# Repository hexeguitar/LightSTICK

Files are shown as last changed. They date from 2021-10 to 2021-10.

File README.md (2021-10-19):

# LightStick

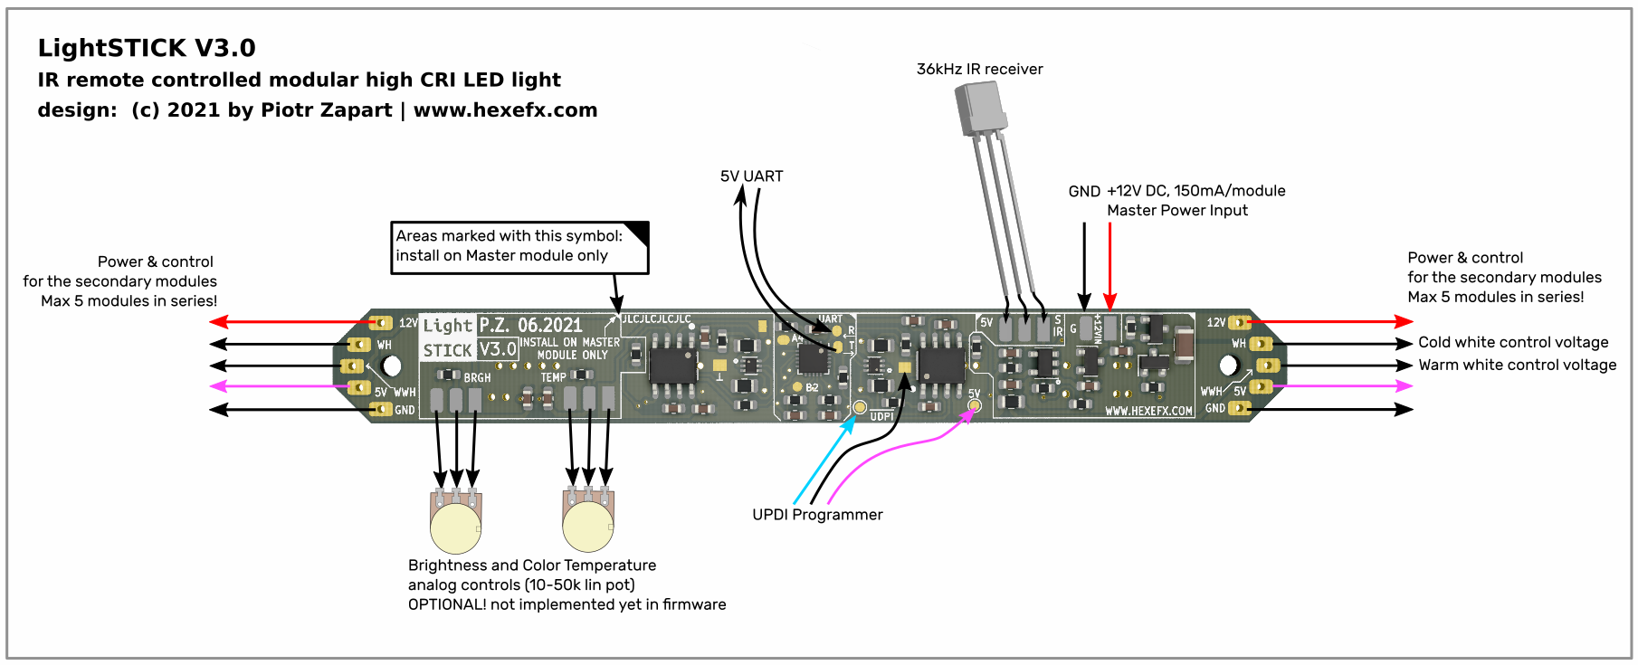
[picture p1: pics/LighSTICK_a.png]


## Features:  
- High CRI >95 dual color white leds (cold/warm).
- Modular system with one Master module and up to 4 secondary modules.
- Linear constant current LED drivers.
- IR remote control (brightness, color, presets).
- Optional analog control using potentiometers (not implemented yet).
- Power saving OFF mode.
- Current consumption: about 300mA per module in full brightness.
  
## Background/design:
Traditional and common studio lights used in photography and filming usually use a high current PWM to control the brightness. For my use in filming analog instruments and effects (often high gain ones) i really needed something quiet and as noise/EMI free as possible.  
That's how the **LightSTICK** modular light was born - it uses linear constant current drivers for the LEDs and a DC control voltage to set the brightness and the color temperature.  
## Modularity
The design is modular, one "Master" module, consisting the MCU and IR receiver can control up to 4 additional secondary modules connected via a 5 wire bus:  
* 12V supply for the LEDs
* 5V supply for the constant current drivers / control voltage reference
* **WH** - cold white control voltage
* **WWH** - warm white control voltage
* GND  
## LED type  
LEDs used in the LightSTICK are manufactured by the LEDGUON company, obtainable through their direct store at Aliexpress.  
The part number is: **JH-5054WWW12S35-T8A-97**
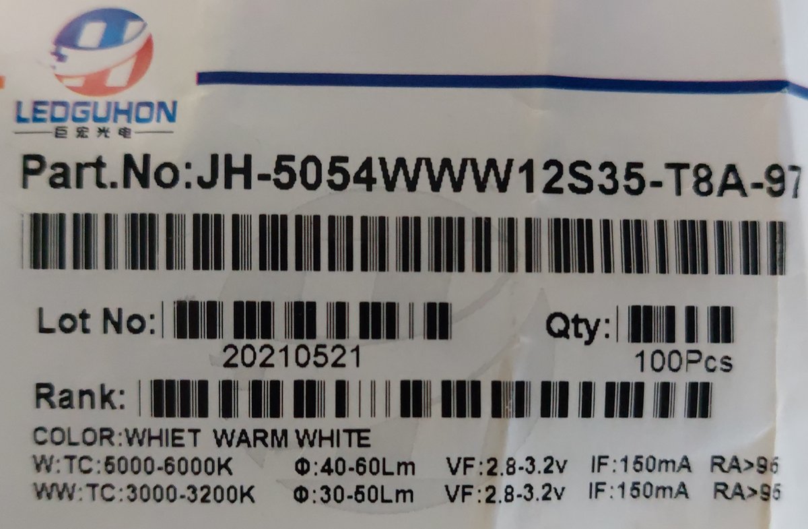
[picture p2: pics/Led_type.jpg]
  

## PCB design
PCB is designed as 4 layer one, using the most of the top layer for heat dissipation.  
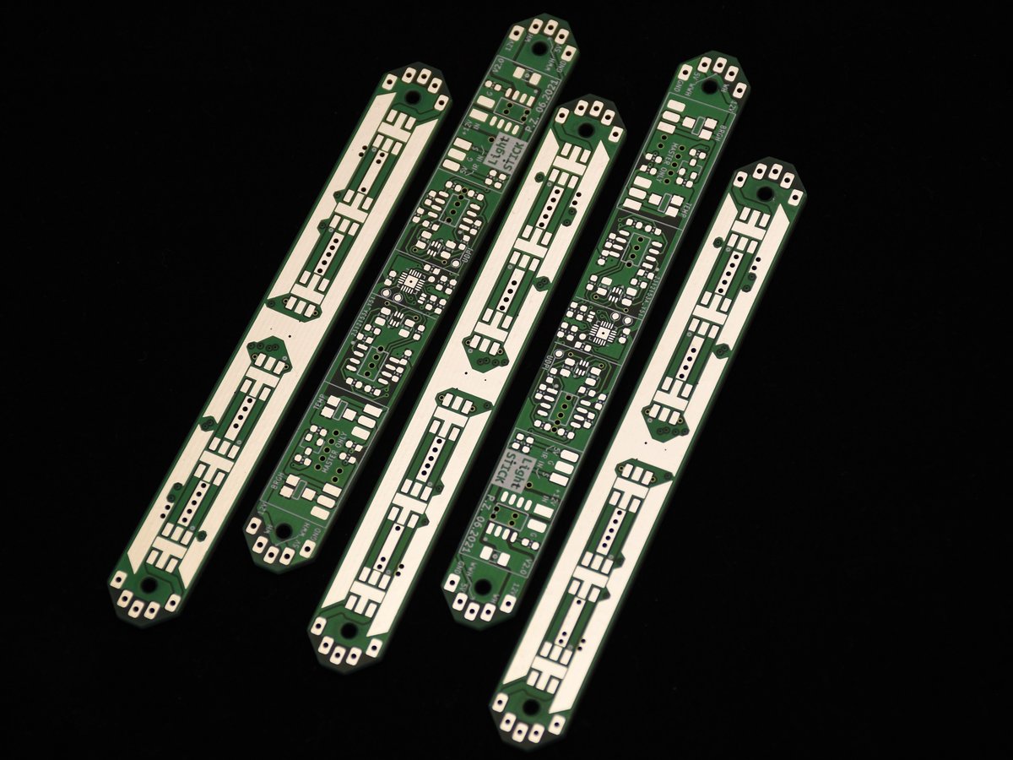
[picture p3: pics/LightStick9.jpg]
  
## Firmware
LightSTICK uses ATtiny806 as it's MCU. The firmware is available as Platformio project and compiled with Arduino framework. Only one library is required and included in the /lib folder: **Arduino-IRremote**, which has been modified to support the ATtiny806 chip.  

### Pot support
Initially i planned to use two potentiometers as control input for the brightness and color temp. However, during the firmware development the IR remote control turned out to be much more useful, hence i went that route. Nevertheless, the footprint for pots are provided and a basic interrupt driven ADC read functionality is implemented in case some would need it. Expanding the firmware should not be a hard task.  

### IR remote control
The easiest way to adapt an existing tv/camera remote as LightSTICK controller is to analyze it using a generic arduino board and one of the examples from the **Arduino-IRremote** library (ie. "Receive Demo). Simply write down the protocol of the remote and all the command codes for each button. In my case of a small remote from an old TC card the results were as follows:  
```
Protocol:           RC5

...
+:                  Command=0x3 Toggle=1 Raw-Data=0x19C3
                    Command=0x3 Raw-Data=0x11C3

-:                  Command=0x9 Toggle=1 Raw-Data=0x19C9
                    Command=0x9 Raw-Data=0x11C9

Up:                 Command=0x6 Toggle=1 Raw-Data=0x19C6
                    Command=0x6 Raw-Data=0x11C6
                    
Down:               Command=0xC Toggle=1 Raw-Data=0x19CC
                    Command=0xC Raw-Data=0x11CC

1:                  Command=0xF Toggle=1 Raw-Data=0x19CF
                    Command=0xF Raw-Data=0x11CF

2:                  Command=0x15 Raw-Data=0x11D5
                    Command=0x15 Toggle=1 Raw-Data=0x19D5

3:                  Command=0x10 Toggle=1 Raw-Data=0x19D0
                    Command=0x10 Raw-Data=0x11D0

4:                  Command=0x18 Raw-Data=0x11D8
                    Command=0x18 Toggle=1 Raw-Data=0x19D8

5:                  Command=0x1B Toggle=1 Raw-Data=0x19DB
                    Command=0x1B Raw-Data=0x11DB
...
```
The command codes are then used in the IR command table (*`remote.h`* file)
```c++
/**
 * @brief IR remote command table. 
 * 
 */
typedef enum
{
    CMD_IDLE            = 0x00,
    CMD_PWR_TGL         = 0x39,     // key POWER
    CMD_BRIGHT_INC      = 0x03,     // key +
    CMD_BRIGHT_DEC      = 0x09,     // key -
    CMD_BRIGHT_MAX      = 0x30,     // key PLAY
    CMD_COLOR_WARMER    = 0x06,     // key UP
    CMD_COLOR_COLDER    = 0x0C,     // key DOWN
    CMD_COLOR_WARM      = 0x33,     // key FWD
    CMD_COLOR_COLD      = 0x2D,     // key REW
    CMD_PRESET_0        = 0x27,     // key 0
    CMD_PRESET_1        = 0x0F,     // key 1
    CMD_PRESET_2        = 0x15,     // key 2
    CMD_PRESET_3        = 0x10,     // key 3
    CMD_PRESET_4        = 0x18,     // key 4
    CMD_PRESET_5        = 0x1B,     // key 5
    CMD_PRESET_6        = 0x1E,     // key 6
    CMD_PRESET_7        = 0x11,     // key 7
    CMD_PRESET_8        = 0x21,     // key 8
    CMD_PRESET_9        = 0x12,     // key 9
    CMD_RESET_MCU       = 0x3C,     // key STOP
    CMD_STORE_PRESET    = 0x36      // key REC
}ir_cmd_t;
```  
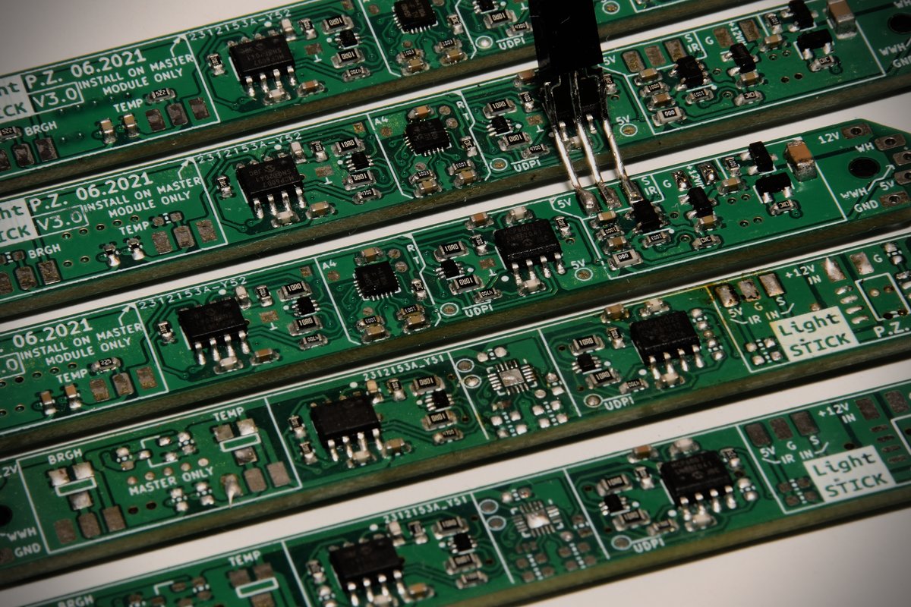
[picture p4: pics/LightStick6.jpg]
  
### Low power design  
Both, the electronics and the firmware implements low power design techniques making the LightSTICK useful as battery operated device, too.  
In **OFF** state the global 12V and 5V power busses are disabled, the MCU is in power off state, practically leaving the IR receiver as a single powered on device.

### Programming
ATtiny806 uses UPDI protocol for programming the flash. The programmer should be connected to the pads marked !UPDI, 5V and GND, depending on the used device. Programmers like the Atmel-ICE require the 5V VDD to set the proper logic level.  
An UPDI programmer can be also made of a generic Arduino board. In that case make sure the board runs on 5V, only the UPDI and GND connections will be required.  
The `platformio.ini` file assumes the Atmel-ICE programmer. This file has to be modified if another type of programmer is used.      
First use the following command in Platformio to set the correct fuse values:  
```
pio run -t fuses -e set_fuses
```
and then normally upload the firmware.  

## Applications  
Cheap "book lamp" rebuilt into remote controlled high CRI light for macro photography. Improved thermals by mounting the pcbs on two pieces of 15mm wide alu flat profile with 3mm thick silicon pad isolation.
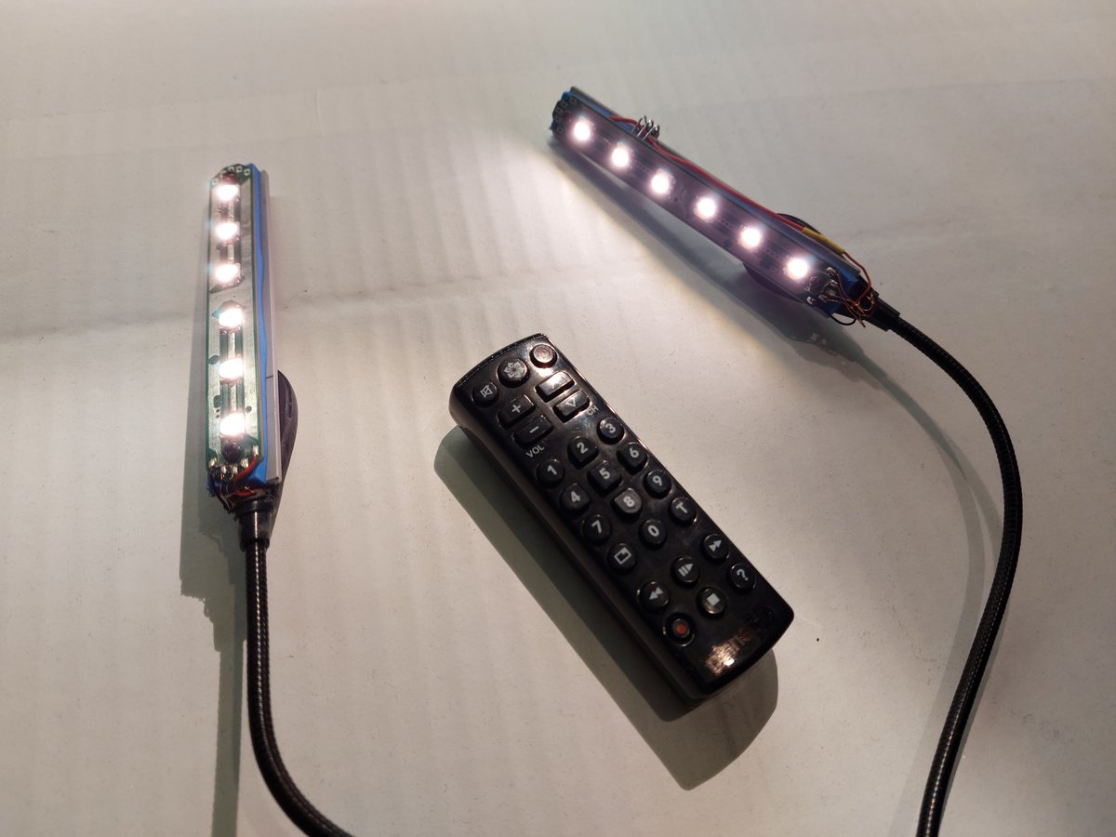
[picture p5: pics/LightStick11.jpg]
  
A ring of 5 LightSTICKs used as source of indirect light in macro photography.
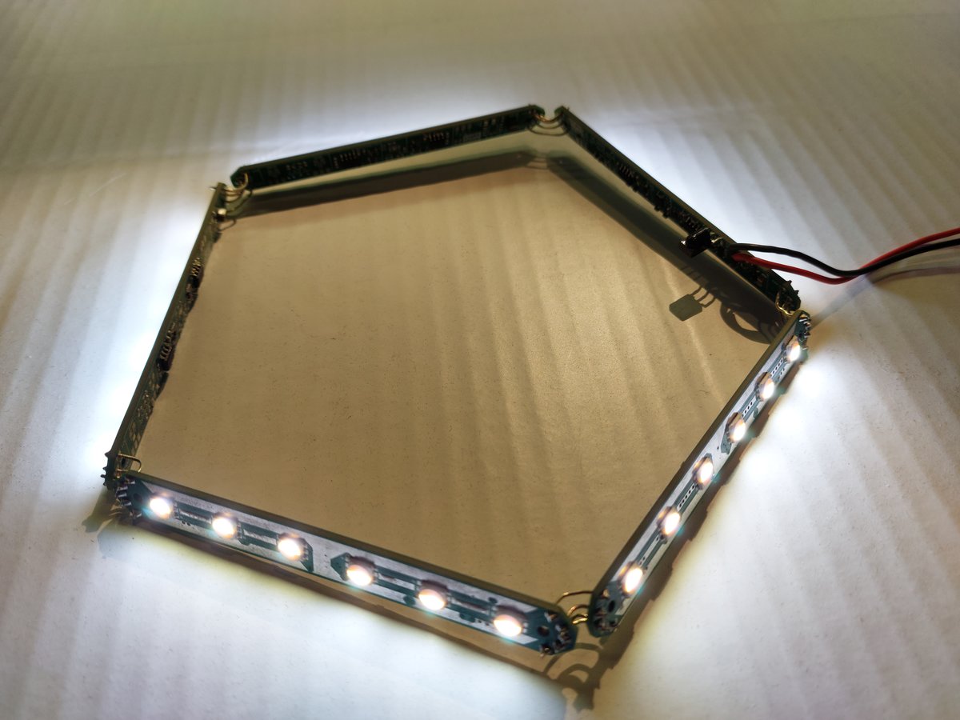
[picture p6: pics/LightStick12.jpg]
  
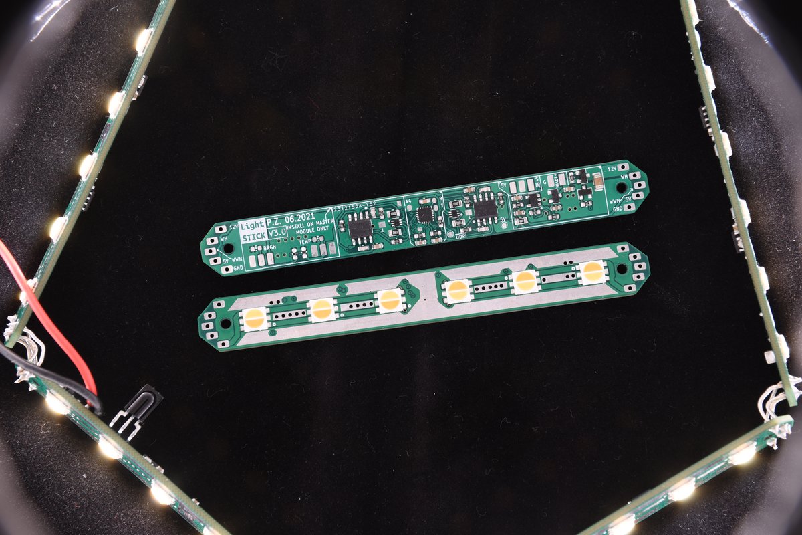
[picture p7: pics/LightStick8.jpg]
  

----  
Copyright 2021 by Piotr Zapart  
www.hexefx.com

[pic1]: pics/LighSTICK_a.png "LightSTICK main"
[pic2]: pics/Led_type.jpg "LEDs used in the project"
[pic3]: pics/LightStick9.jpg "LightSTICK"
[pic4]: pics/LightStick8.jpg "LightSTICK"
[pic5]: pics/LightStick6.jpg "LightSTICK"
[pic6]: pics/LightStick11.jpg "LightSTICK"
[pic7]: pics/LightStick12.jpg "LightSTICK"

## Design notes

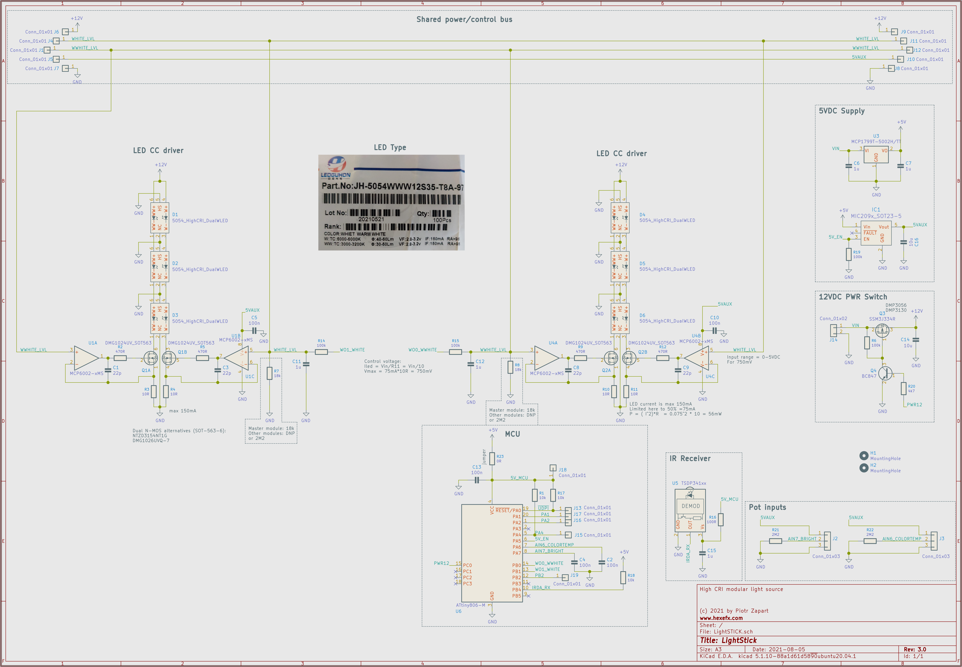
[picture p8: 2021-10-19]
hardware/LightSTICK_V3_schm.png

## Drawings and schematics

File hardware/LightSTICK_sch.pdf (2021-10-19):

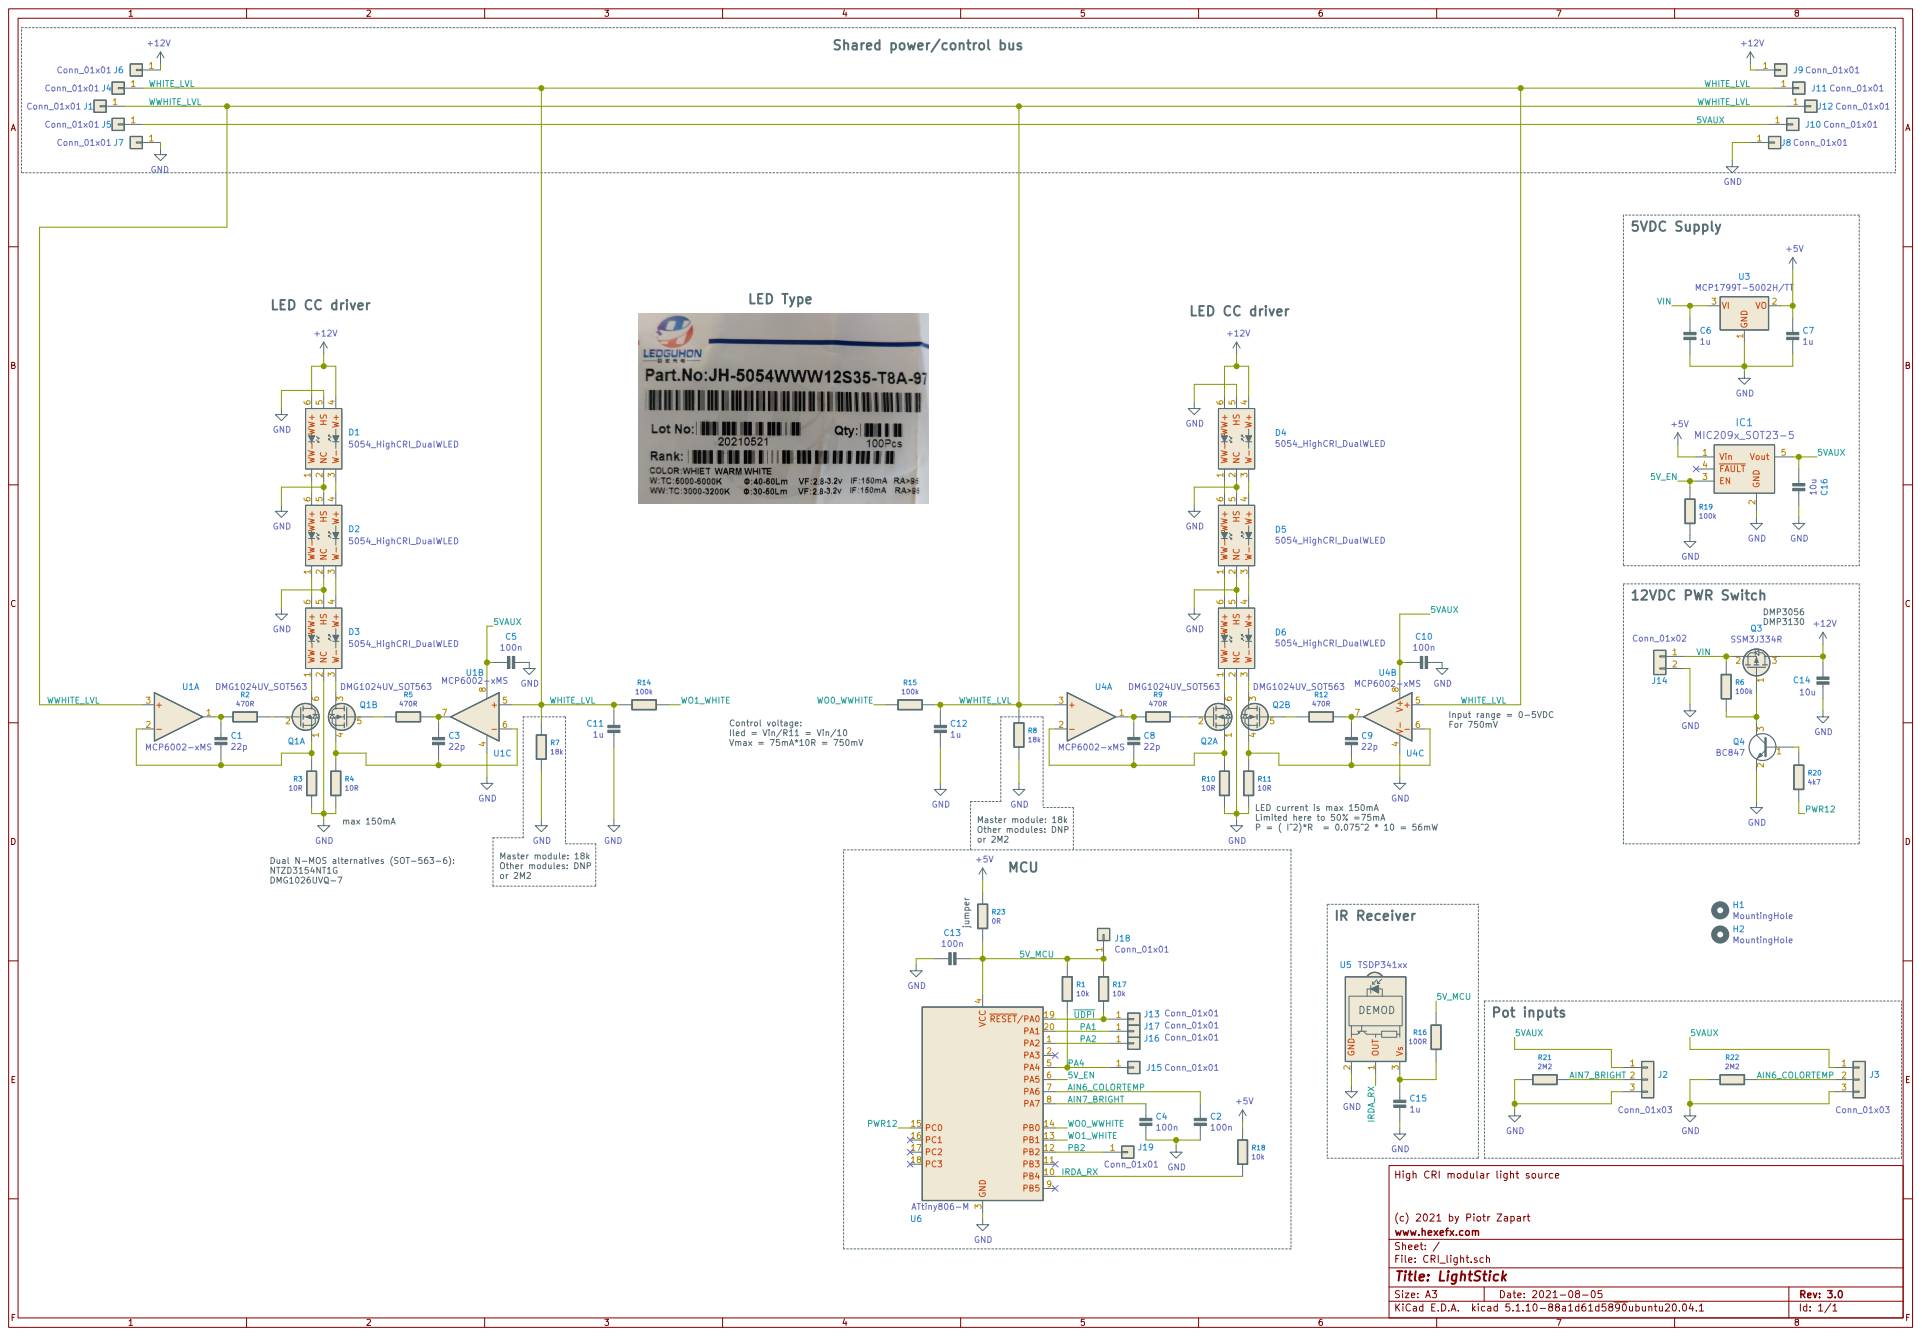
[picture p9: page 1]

Shared power/control bus

Iled = Vin/R11 = Vin/10 Vmax = 75mA*10R = 750mV LED CC driver

10uGND GND GND GND GND GND

Master module: 18k Other modules: DNP

Dual N-MOS alternatives (SOT-563-6): NTZD3154NT1G

High CRI modular light source

(c) 2021 by Piotr Zapart
File: CRI_light.sch Sheet: / www.hexefx.com

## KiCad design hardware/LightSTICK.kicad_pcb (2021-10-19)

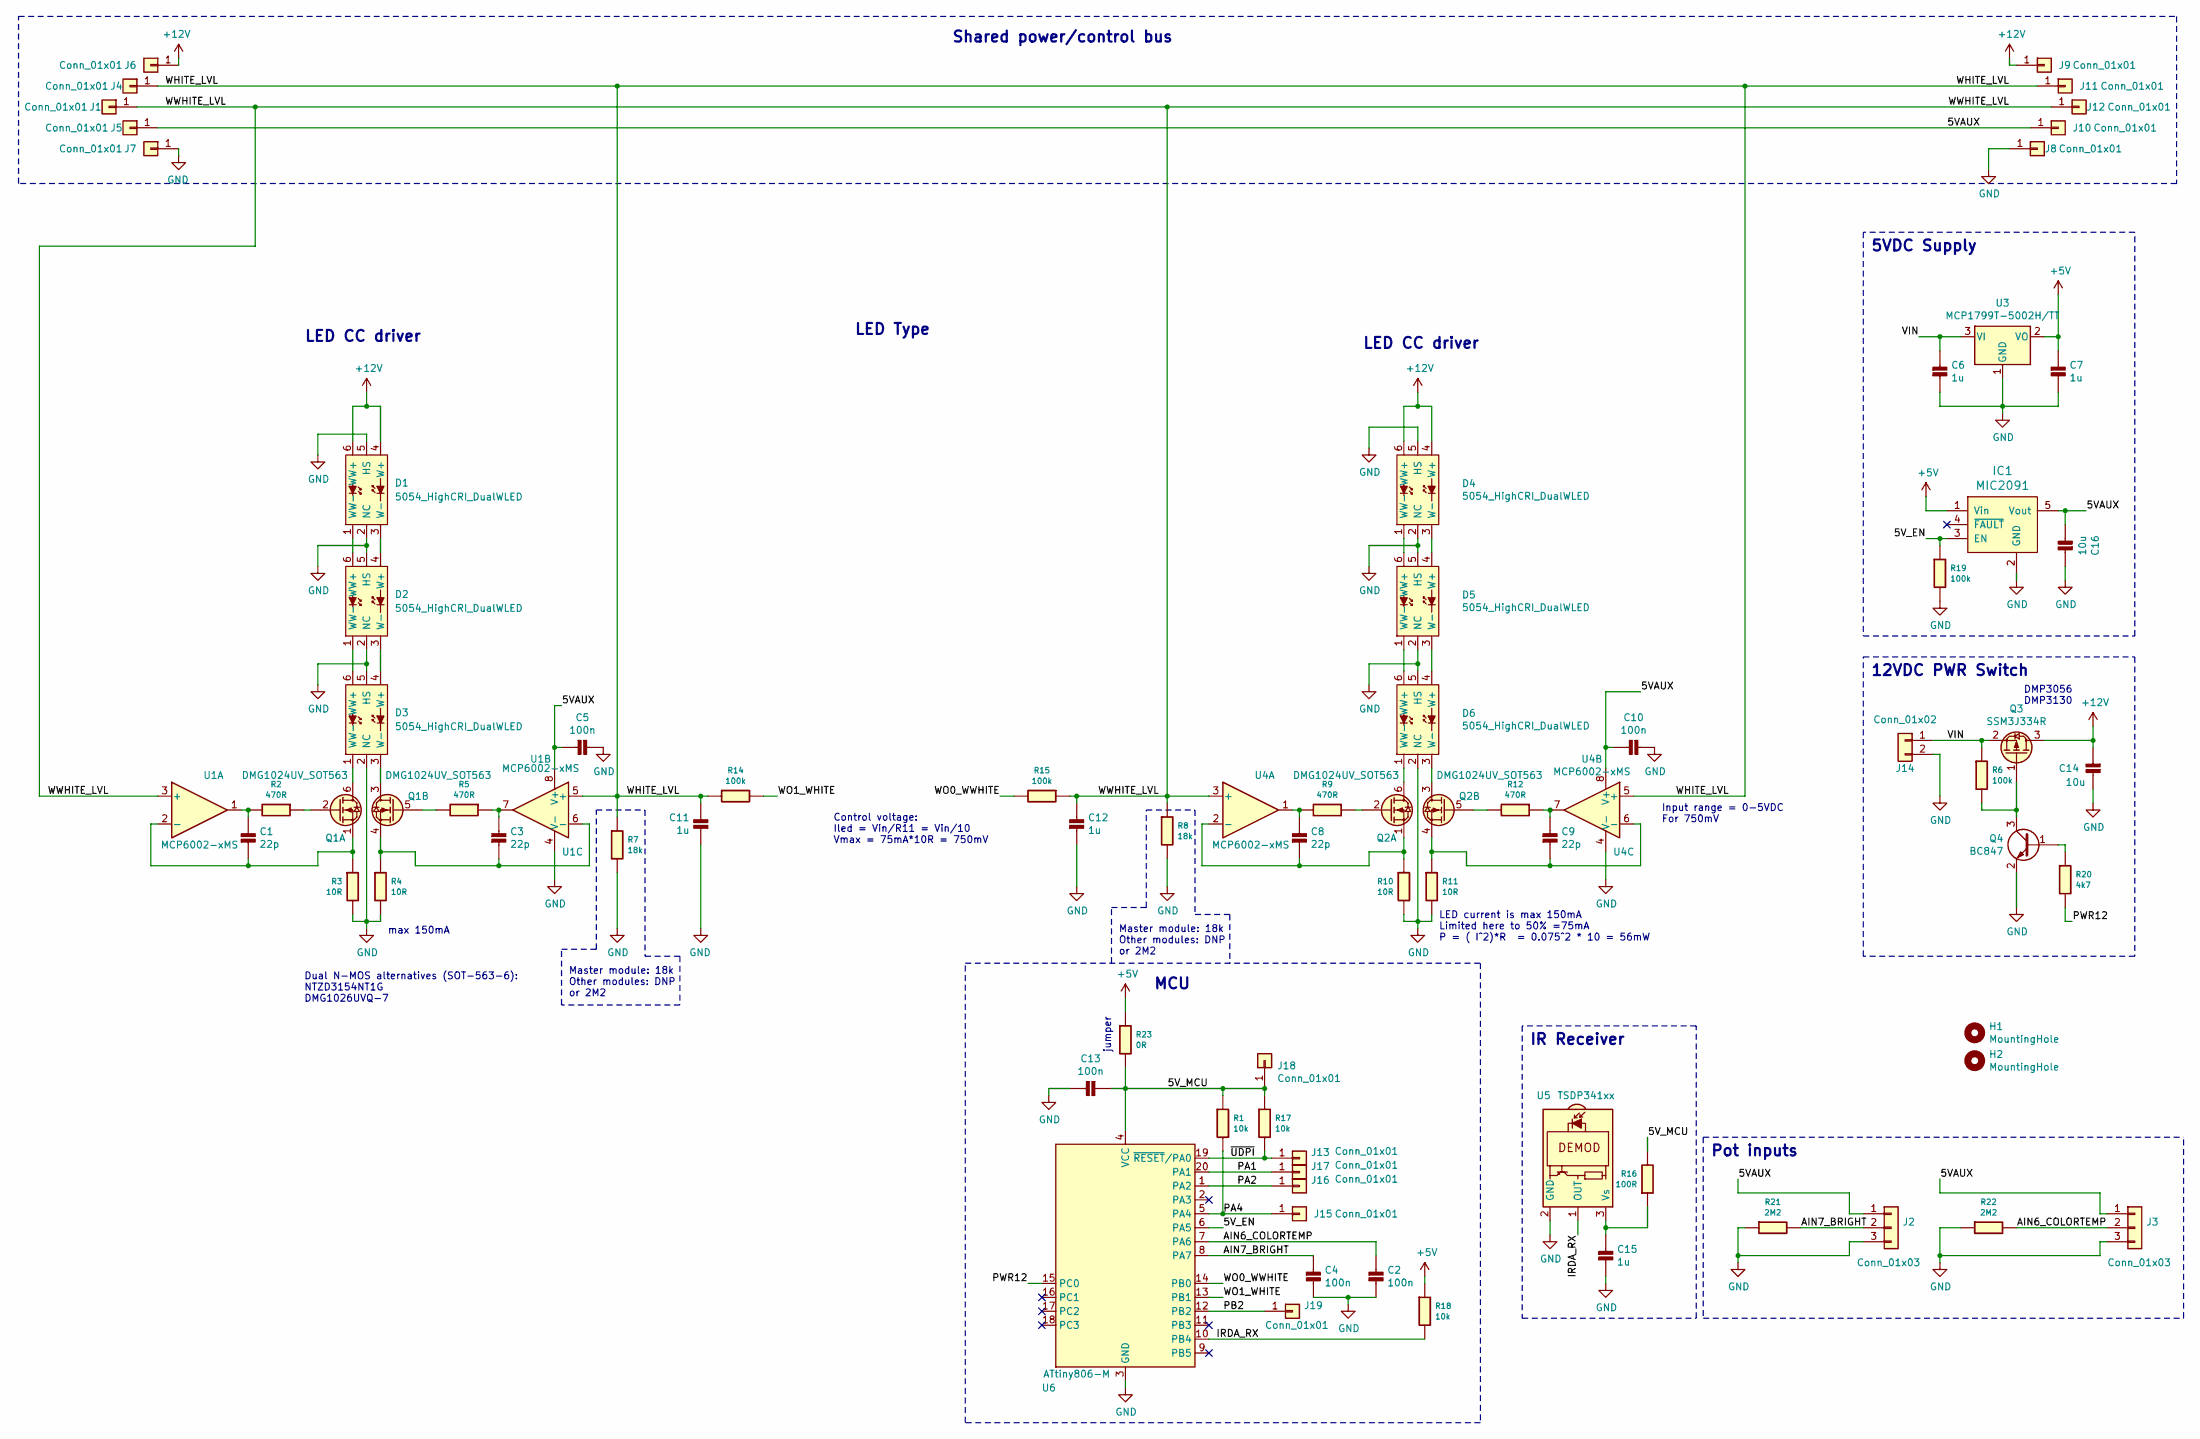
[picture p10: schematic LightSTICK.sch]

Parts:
C1, C3, C8, C9: 22p; Hx_C_0603_1608Metric
C2, C4, C5, C10, C13: 100n; Hx_C_0603_1608Metric
C6, C7, C11, C12, C15: 1u; Hx_C_0603_1608Metric
C14: 10u; Hx_C_1206_3216Metric
C16: 10u; Hx_C_0603_1608Metric
D1, D2, D3, D4, D5, D6: 5054_HighCRI_DualWLED; LED_HighCRI_WhiteWarmWhite_5.0x5.0mm_P1.0mm
H1, H2: MountingHole; MountingHole_2.2mm_M2
IC1: MIC2091; SOT-23-5
J1, J4, J5, J6, J7, J8, J9, J10, J11, J12: Conn_01x01; 1x1_1.5x0.8_square
J2, J3: Conn_01x03; PinHeader_1x03_P2.00mm_SMDpads
J13, J15, J16, J17, J18, J19: Conn_01x01; TestPoint_Pad_D1.0mm
J14: Conn_01x02; PinHeader_1x02_P2.54mm_SMDpads
Q1, Q2: DMG1024UV_SOT563; SOT-563
Q3: SSM3J334R; SOT-23
Q4: BC847; SOT-23
R1, R17, R18: 10k; Hx_R_0603_1608Metric
R2, R5, R9, R12: 470R; Hx_R_0603_1608Metric
R3, R4, R10, R11: 10R; Hx_R_0805_2012Metric
R6, R14, R15, R19: 100k; Hx_R_0603_1608Metric
R7, R8: 18k; Hx_R_0603_1608Metric
R16: 100R; Hx_R_0603_1608Metric
R20: 4k7; Hx_R_0603_1608Metric
R21, R22: 2M2; Hx_R_0603_1608Metric
R23: 0R; Hx_R_0805_2012Metric
U1, U4: MCP6002-xMS; SOIC8
U3: MCP1799T-5002H/TT; SOT-23
U5: TSDP341xx; PinHeader_1x03_P2.00mm_SMDpads
U6: ATtiny806-M; VQFN-20-1EP_3x3mm_P0.4mm_EP1.7x1.7mm

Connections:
+5V: C7.1, IC1.1 (Vin), R18.1, R23.1, U3.2 (VO)
+12V: C14.2, D1.4 (W+), D1.6 (WW+), D4.4 (W+), D4.6 (WW+), J6.1, J9.1, Q3.3 (D)
/5VAUX: C5.2, C10.2, C16.2, IC1.5 (Vout), J2.1, J3.1, J5.1, J10.1, U1.8 (V+), U4.8 (V+)
/5V_EN: IC1.3 (EN), R19.1, U6.6 (PA5)
/5V_MCU: C13.2, J18.1, R1.1, R16.2, R17.1, R23.2, U6.4 (VCC)
/AIN6_COLORTEMP: C2.1, J3.2, R22.2, U6.7 (PA6)
/AIN7_BRIGHT: C4.1, J2.2, R21.2, U6.8 (PA7)
/IRDA_RX: R18.2, U5.1 (OUT), U6.10 (PB4)
/PA1: J17.1, U6.20 (PA1)
/PA2: J16.1, U6.1 (PA2)
/PA4: J15.1, R1.2, U6.5 (PA4)
/PB2: J19.1, U6.12 (PB2)
/PWR12: R20.2, U6.15 (PC0)
/VIN: C6.1, J14.1, Q3.2 (S), R6.1, U3.3 (VI)
/WHITE_LVL: C11.1, J4.1, J11.1, R7.1, R14.1, U1.5 (+), U4.5 (+)
/WO0_WWHITE: R15.2, U6.14 (PB0)
/WO1_WHITE: R14.2, U6.13 (PB1)
/WWHITE_LVL: C12.1, J1.1, J12.1, R8.1, R15.1, U1.3 (+), U4.3 (+)
/~UDPI: J13.1, R17.2, U6.19 (~RESET~/PA0)
GND: C2.2, C4.2, C5.1, C6.2, C7.2, C10.1, C11.2, C12.2, C13.1, C14.1, C15.2, C16.1, D1.2 (NC), D1.5 (HS), D2.2 (NC), D2.5 (HS), D3.2 (NC), D3.5 (HS), D4.2 (NC), D4.5 (HS), D5.2 (NC), D5.5 (HS), D6.2 (NC), D6.5 (HS), IC1.2 (GND), J2.3, J3.3, J7.1, J8.1, J14.2, Q4.2 (E), R3.2, R4.2, R7.2, R8.2, R10.2, R11.2, R19.2, R21.1, R22.1, U1.4 (V-), U3.1 (GND), U4.4 (V-), U5.2 (GND), U6.3 (GND), U6.21 (GND)
unnamed: C1.1, R2.2, U1.1
unnamed: C1.2, Q1.1 (S), R3.1, U1.2 (-)
unnamed: C3.1, R5.1, U1.7
unnamed: C3.2, Q1.4 (S), R4.1, U1.6 (-)
unnamed: C8.1, R9.2, U4.1
unnamed: C8.2, Q2.1 (S), R10.1, U4.2 (-)
unnamed: C9.1, R12.1, U4.7
unnamed: C9.2, Q2.4 (S), R11.1, U4.6 (-)
unnamed: C15.1, R16.1, U5.3 (Vs)
unnamed: D1.1 (WW-), D2.6 (WW+)
unnamed: D1.3 (W-), D2.4 (W+)
unnamed: D2.1 (WW-), D3.6 (WW+)
unnamed: D2.3 (W-), D3.4 (W+)
unnamed: D3.1 (WW-), Q1.6 (D)
unnamed: D3.3 (W-), Q1.3 (D)
unnamed: D4.1 (WW-), D5.6 (WW+)
unnamed: D4.3 (W-), D5.4 (W+)
unnamed: D5.1 (WW-), D6.6 (WW+)
unnamed: D5.3 (W-), D6.4 (W+)
unnamed: D6.1 (WW-), Q2.6 (D)
unnamed: D6.3 (W-), Q2.3 (D)
unnamed: Q1.2 (G), R2.1
unnamed: Q1.5 (G), R5.2
unnamed: Q2.2 (G), R9.1
unnamed: Q2.5 (G), R12.2
unnamed: Q3.1 (G), Q4.3 (C), R6.2
unnamed: Q4.1 (B), R20.1

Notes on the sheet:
max 150mA
LED current is max 150mA Limited here to 50% =75mA P = ( I^2)*R = 0.075^2 * 10 = 56mW
Control voltage: Iled = Vin/R11 = Vin/10 Vmax = 75mA*10R = 750mV
Shared power/control bus
LED CC driver
Pot inputs
MCU
5VDC Supply
Input range = 0-5VDC For 750mV
Dual N-MOS alternatives (SOT-563-6): NTZD3154NT1G DMG1026UVQ-7
12VDC PWR Switch
jumper
IR Receiver
DMP3056 DMP3130
Master module: 18k Other modules: DNP or 2M2
LED Type

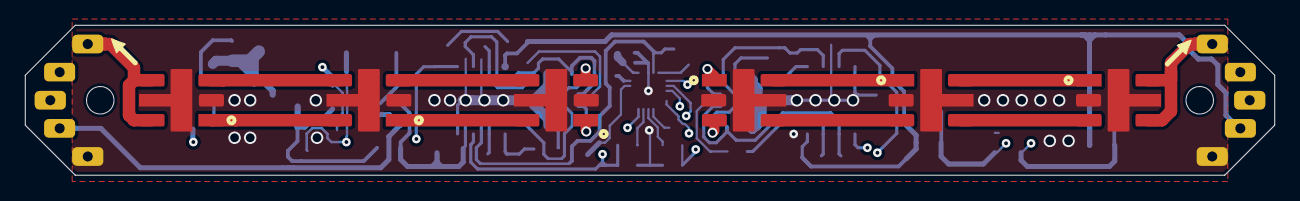
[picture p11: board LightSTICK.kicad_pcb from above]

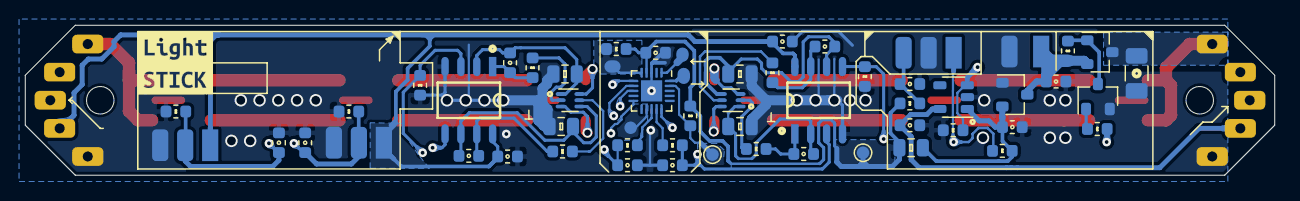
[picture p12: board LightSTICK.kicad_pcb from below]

Board: 4 copper layers, 100.0 x 12.0 mm, 76 parts (68 on the bottom side), 47 nets.

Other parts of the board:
svg2mod: G***; label

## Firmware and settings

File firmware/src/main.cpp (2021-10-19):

/*
 * Copyright (c) 2021 by Piotr Zapart / www.hexefx.com
 *
 * All rights reserved.
 *
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
 * Neither the name of the Piotr Zapart or HEXE FX nor the names of its 
 * contributors may be used to endorse or promote products derived from this software 
 * without specific prior written permission.
 * 
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
 */
#include <Arduino.h>
#include "leds.h"
#include "pots.h"
#include "power.h"
#include "remote.h"
#include "Wire.h"


ir_cmd_t ir_cmd;

void setup()
{
    Serial.swap(1);         // use alternate pin mapping
    Serial.begin(115200);
    Serial.println(F("LightSTICK"));
    pwr_init();
    leds_init();
    remote_init();
    pwr_off();
}

void loop()
{

    ir_cmd = remote_process();
    switch (ir_cmd)
    {
    case CMD_IDLE:
        break;
    case CMD_PWR_TGL:
        switch (leds_get_state())
        {
            case LEDS_PWR_OFF:
            case LEDS_WAKE_UP:
                leds_set_state(LEDS_PWR_ON);
                break;
            case LEDS_PWR_ON:
                pwr_off();
                break;        
            default:
                break;
        }
        break;
    case CMD_BRIGHT_INC:
        leds_brightness_inc();
        break;
    case CMD_BRIGHT_DEC:
        leds_brightness_dec();
        break;
    case CMD_BRIGHT_MAX:
        leds_set_max();
        break;
    case CMD_COLOR_WARMER:
        leds_colortemp_warm();
        break;
    case CMD_COLOR_COLDER:
        leds_colortemp_cold();
        break;
    case CMD_PRESET_0:
        leds_set_preset(0);
        break;
    case CMD_PRESET_1:
        leds_set_preset(1);
        break;
    case CMD_PRESET_2:
        leds_set_preset(2);
        break;
    case CMD_PRESET_3:
        leds_set_preset(3);
        break;
    case CMD_PRESET_4:
        leds_set_preset(4);
        break;
    case CMD_PRESET_5:
        leds_set_preset(5);
        break;
    case CMD_PRESET_6:
        leds_set_preset(6);
        break;
    case CMD_PRESET_7:
        leds_set_preset(7);
        break;
    case CMD_PRESET_8:
        leds_set_preset(8);
        break;
    case CMD_PRESET_9:
        leds_set_preset(9);
        break;
    case CMD_RESET_MCU:
        _PROTECTED_WRITE(RSTCTRL.SWRR,1);
        break;
    default:
        break;
    }

    leds_process();


}

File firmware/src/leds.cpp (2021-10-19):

/*
 * Copyright (c) 2021 by Piotr Zapart / www.hexefx.com
 *
 * All rights reserved.
 *
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
 * Neither the name of the Piotr Zapart or HEXE FX nor the names of its 
 * contributors may be used to endorse or promote products derived from this software 
 * without specific prior written permission.
 * 
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
 */
#include "leds.h"
#include <EEPROM.h>

#define WARM_PIN PIN_PB0
#define COLD_PIN PIN_PB1

#define EEP_FACT_MARKER         (0xA512)
#define AUTOSAVE_DELAY_MS       (10000l)    // 10 sec delay to save last used preset in eeprom

// EEPROM addresses
uint8_t EEMEM eep_preset_table[2*10];
uint8_t EEMEM eep_last_preset;
uint16_t EEMEM eep_fact_marker;


const uint8_t fact_preset_table[2*10] = 
{
    0x10, 0x7F,         // Preset 0 = 10% bright, cold+warm white
    0xFF, 0x00,         // Preset 1 = 100% bright, cold white
    0x7F, 0x00,         // Preset 2 = 50% bright, cold white
    0x33, 0x00,         // Preset 3 = 20% bright, cold white
    0xFF, 0xFF,         // Preset 4 = 50% bright, warm white
    0x7F, 0xFF,         // Preset 5 = 20% bright, warm white
    0x33, 0xFF,         // Preset 6 = 100% bright, cold+warm white
    0xFF, 0x7F,         // Preset 7 = 100% bright, cold+warm white
    0x7F, 0x7F,         // Preset 8 = 100% bright, cold+warm white
    0x33, 0x7F          // Preset 9 =  bright, cold+warm white
};

// ----------------------------------------------------------------------------
// lastly used settings, stored in EEPROM and read on start
uint8_t last_brightness;
uint8_t last_colortemp;
uint8_t current_preset = 1;

leds_state_t state = LEDS_PWR_OFF;
bool mark_for_save = false;
uint32_t save_timestamp;
uint32_t wakeup_timestamp;

void leds_set(uint8_t bright, uint8_t color, bool store);

// ----------------------------------------------------------------------------
/**
 * @brief Initialize leds related stuff, 
 *          populate eeprom with default values on 1st boot
 * 
 */
void leds_init(void)
{

    uint16_t marker = eeprom_read_word(&eep_fact_marker);
    Serial.println(marker, HEX);
    // factory reset on 1st boot
    if (marker != EEP_FACT_MARKER)
    {
        Serial.println(F("Factory reset"));
        eeprom_write_block(fact_preset_table, eep_preset_table, sizeof(eep_preset_table)); // write the factory data to eeprom
        eeprom_busy_wait();
        eeprom_write_byte(&eep_last_preset, 0x01);                                         // default preset = 1
        eeprom_busy_wait();
        current_preset = 1;
        eeprom_write_word(&eep_fact_marker, EEP_FACT_MARKER);
        eeprom_busy_wait();
    }
    current_preset = eeprom_read_byte(&eep_last_preset);
    last_brightness = eeprom_read_byte(&eep_preset_table[current_preset*2]);
    last_colortemp = eeprom_read_byte(&eep_preset_table[(current_preset*2)+1]);
    // congif the pins:
    pinMode(WARM_PIN, OUTPUT);
    pinMode(COLD_PIN, OUTPUT);
    state = LEDS_PWR_OFF;
    leds_set(0x00, 0X00, false);
}
// ----------------------------------------------------------------------------
/**
 * @brief Increase brightness in steps defined in leds.h
 * 
 */
void leds_brightness_inc(void)
{
    state = LEDS_PWR_ON;
    if (last_brightness <= 0xFF-LEDS_BRIGHTNESS_STEP)    last_brightness += LEDS_BRIGHTNESS_STEP;
    else                                                last_brightness = 0xFF;
    leds_set(last_brightness, last_colortemp, true);
}
// ----------------------------------------------------------------------------
/**
 * @brief Decrease brightness in steps defined in leds.h
 * 
 */
void leds_brightness_dec(void)
{
    state = LEDS_PWR_ON;
    if (last_brightness >= LEDS_BRIGHTNESS_STEP)        last_brightness -= LEDS_BRIGHTNESS_STEP;
    else                                                last_brightness = 0x00;
    leds_set(last_brightness, last_colortemp, true);
}
// ----------------------------------------------------------------------------
/**
 * @brief Change color temperature cold--->warm
 * 
 */
void leds_colortemp_warm(void)
{
    state = LEDS_PWR_ON;
    if (last_colortemp <= 0xFF-LEDS_COLORTEMP_STEP)      last_colortemp += LEDS_COLORTEMP_STEP;
    else                                                last_colortemp = 0xFF;
    leds_set(last_brightness, last_colortemp, true);
}
// ----------------------------------------------------------------------------
/**
 * @brief Change color temperature warm--->cold
 * 
 */
void leds_colortemp_cold(void)
{
    state = LEDS_PWR_ON;
    if (last_colortemp >= LEDS_COLORTEMP_STEP)          last_colortemp -= LEDS_BRIGHTNESS_STEP;
    else                                                last_colortemp = 0x00;
    leds_set(last_brightness, last_colortemp, true);
}

// ----------------------------------------------------------------------------
/**
 * @brief set new leds engine state
 * 
 * @param s 
 */
void leds_set_state(leds_state_t s)
{
    state = s;
    switch (state)
    {
        case LEDS_PWR_OFF:
            leds_set(0x00, last_colortemp, false);
            break;
        case LEDS_WAKE_UP:
            wakeup_timestamp = millis();
            leds_set_preset(current_preset);
            break;
        case LEDS_PWR_ON:
            leds_set(last_brightness, last_colortemp, false);
            break;        
        default:
            break;
    }       
}
// ----------------------------------------------------------------------------
leds_state_t leds_get_state(void)
{
    return state;
}
// ----------------------------------------------------------------------------
/**
 * @brief Set the brightness and color of the leds
 * 8 bit values
 * 
 * @param bright    overall brightness level, 8 bit value
 * @param color     mix between cold and warm white, 8 bit value
 */
void leds_set(uint8_t bright, uint8_t color, bool store)
{
    uint16_t t16;
    uint8_t cold, warm;

    if (bright == 0)
    {
        analogWrite(WARM_PIN, 0x00);
        analogWrite(COLD_PIN, 0x00);
        return;
    }

    t16 = ((uint16_t) color * color) >> 6;      // 0-1023

    if (t16 > 0xFF) warm = 0xFF;                 // clamp to 0xFF
    else            warm = t16;
    
    t16 = 511 - (t16>>1);
    if (t16 > 0xFF) cold = 0xFF;
    else            cold = t16;

    warm = ((uint16_t) warm * bright)>>8;       // scale by brightness
    cold = ((uint16_t) cold * bright)>>8; 

    analogWrite(WARM_PIN, warm);
    analogWrite(COLD_PIN, cold);
    if (store)
    {
        last_brightness = bright;
        last_colortemp = color;
    }

}
// ----------------------------------------------------------------------------
/**
 * @brief Both leds at 100% brightness
 * 
 */
void leds_set_max(void)
{
    state = LEDS_PWR_ON;
    leds_set(0xFF, 0x7F, true);
}
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
